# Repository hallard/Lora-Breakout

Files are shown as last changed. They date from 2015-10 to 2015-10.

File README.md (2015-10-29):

RFM92 RFM95 RFM96 RFM98 Lora breakout board NRF24L01 socket
===========================================================

This is a utility breakout board for connecting Lora device onto 
NRF24L01 sockets

this breakout add also some other nice feature : 
- **Added** ATSHA204 for Crypto Authentication.
- **added** a Led to see what's going on.

Breakout comes in two versions, one with classic 2x4 PTH connector and the other with the same
but SMD version of the connector, this permit to have the PCB quite the same size of the original
RFM modules size. Oh, also these boards are rounded instead of corners.

This has been created to work with [ULPNode][7] Project and [ArduiPi][4] Project, but this breakout
can be used anywhere where you use NRF24L01 or has NRF24L01 connector.

The same breakout board exists also for RFM69W and RFM69HW on this [repo][2] and for RFM12B on this [one][1].
 
Check out news and other on my [blog][5], Any comments or question are welcomed on the [community][8]!

Detailed Description
====================

Everything will be soon documented on this dedicated [post][6].

## PTH connector version

### Schematic  
schematic  

### Boards  
board&nbsp;
top&nbsp;
bottom

You can direct order PCB from this [link][10] to OSHPark.

## SMD connector version

### Schematic  
schematic  

### Boards  
board SMD&nbsp;
top SMD&nbsp;
bottom SMD

You can direct order PCB from this [link][11] to OSHPark.

Check out news and other on my [blog][5], Any comments or question are welcomed on the [community][8]!

[1]: https://github.com/hallard/RFM12B-BreakOut
[2]: https://github.com/hallard/RFM69W-BreakOut
[3]: http://hallard.me/rfm12b-breakout/ 
[4]: http://hallard.me/arduipi
[5]: http://hallard.me
[6]: http://hallard.me/lora-breakout/ 
[7]: http://hallard.me/category/ulpnode/
[8]: https://community.hallard.me/
[10]: https://oshpark.com/projects/XCiquSkv/order
[11]: https://oshpark.com/projects/V7WQxHGe/order

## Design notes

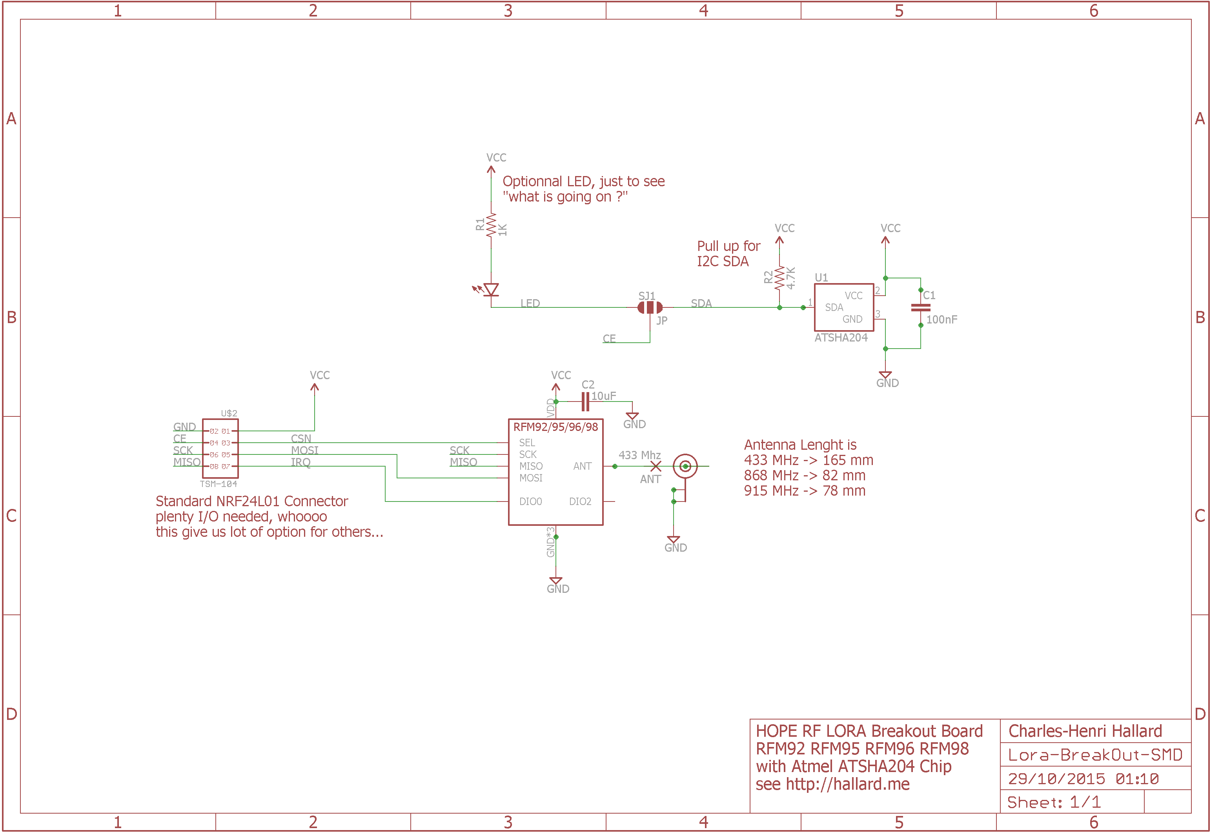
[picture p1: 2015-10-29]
Lora-Breakout-SMD-sch.png

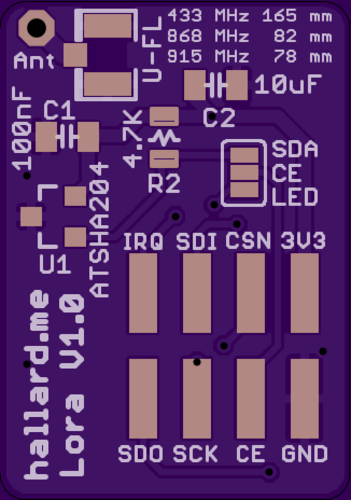
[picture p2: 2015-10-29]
Lora-Breakout-SMD-bot.png

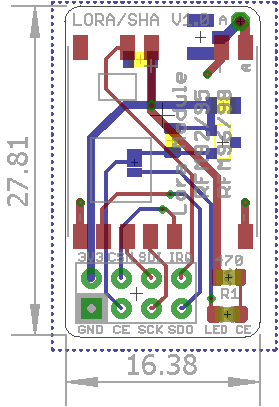
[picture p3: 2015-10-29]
Lora-Breakout-brd.png

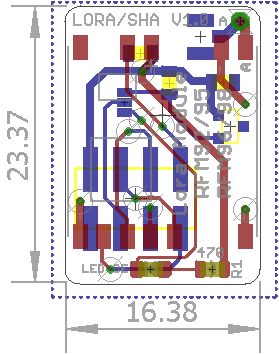
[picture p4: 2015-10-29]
Lora-Breakout-SMD-brd.png

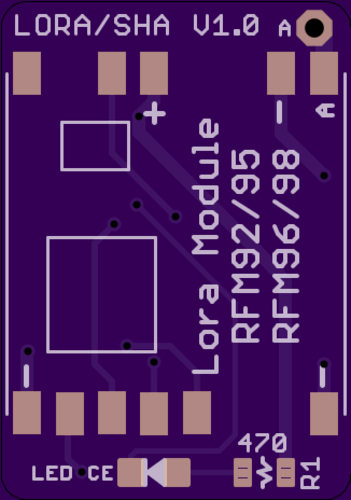
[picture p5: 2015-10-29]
Lora-Breakout-SMD-top.png

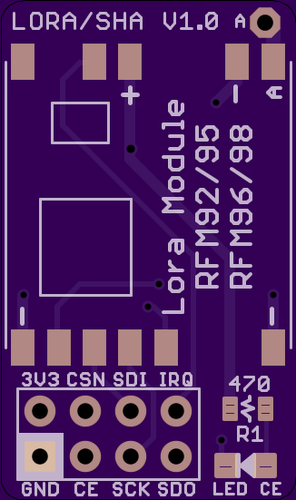
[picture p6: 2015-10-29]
Lora-Breakout-top.png

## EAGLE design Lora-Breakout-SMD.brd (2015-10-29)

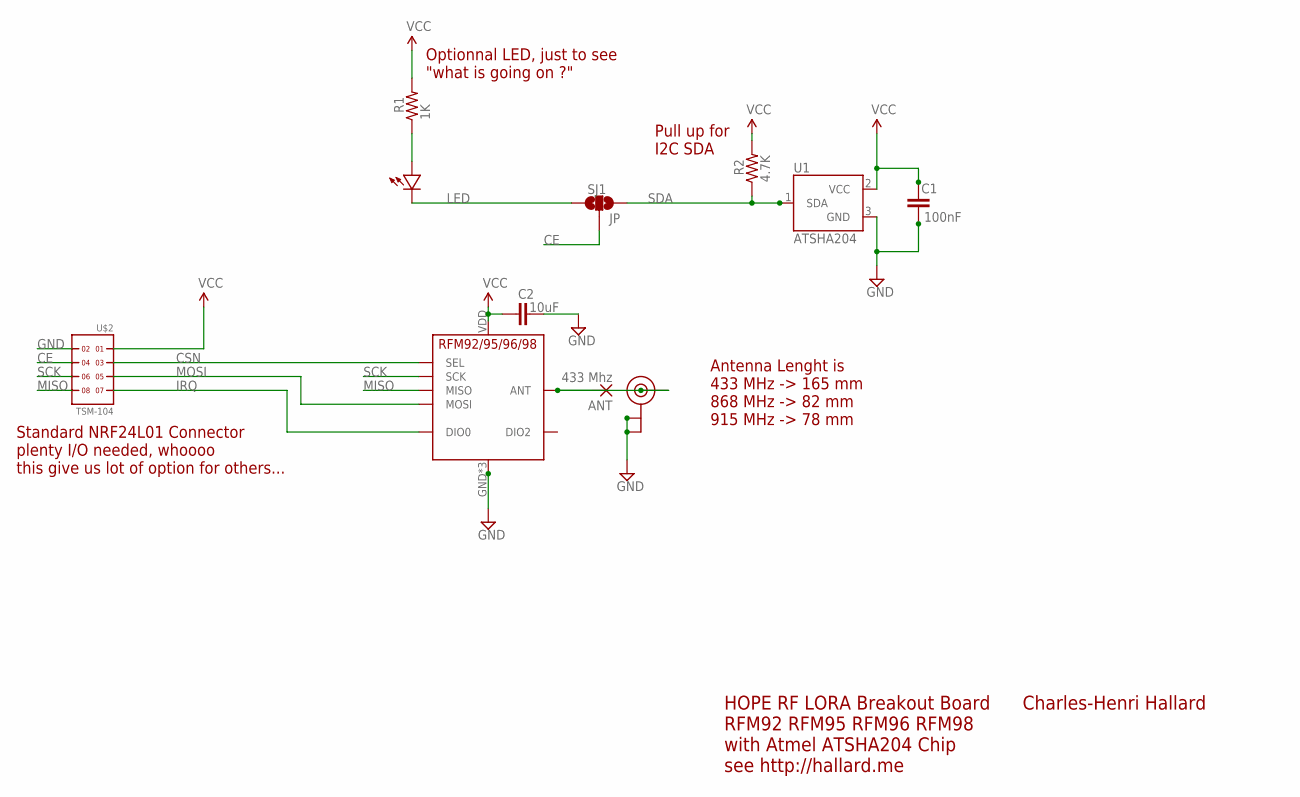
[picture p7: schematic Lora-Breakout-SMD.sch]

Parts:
ANT: 433 Mhz; 1,6/0,8
C1: 100nF; 0805-CAP
C2: 10uF; 0805-CAP
R1: 1K; 0805-RES
R2: 4.7K; 0805-RES
SJ1: JP; PAD-JUMPER-3-NO_YES_SILK
U1: ATSHA204; SOT23-3
U$1: LED0805-LARGE; 0805-LED-LARGEPADS
U$2: TSM-104
U$3: RFM95
U-FL: U.FL

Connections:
CE: SJ1.2, U$2.4
CSN: U$2.3, U$3.NSS (SEL)
GND: C1.2, C2.2, U1.3 (GND), U$2.2, U$3.GND, U$3.GND1 (GND), U$3.GND2 (GND), U-FL.1 (GND), U-FL.2 (GND)
IRQ: U$2.7, U$3.DIO0
LED: SJ1.1, U$1.MINUS
MISO: U$2.8, U$3.MISO
MOSI: U$2.5, U$3.MOSI
unnamed: ANT.1, U$3.ANT, U-FL.3 (SIGNAL)
unnamed: R1.1, U$1.PLUS
SCK: U$2.6, U$3.SCK
SDA: R2.1, SJ1.3, U1.1 (SDA)
VCC: C1.1, C2.1, R1.2, R2.2, U1.2 (VCC), U$2.1, U$3.VDD (VCC)

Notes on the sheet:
HOPE RF LORA Breakout Board RFM92 RFM95 RFM96 RFM98 with Atmel ATSHA204 Chip see http://hallard.me
Charles-Henri Hallard
Antenna Lenght is 433 MHz -> 165 mm 868 MHz -> 82 mm 915 MHz -> 78 mm
Optionnal LED, just to see "what is going on ?"
Standard NRF24L01 Connector plenty I/O needed, whoooo this give us lot of option for others...
Pull up for I2C SDA

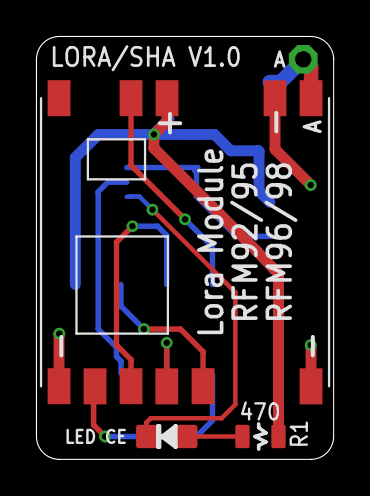
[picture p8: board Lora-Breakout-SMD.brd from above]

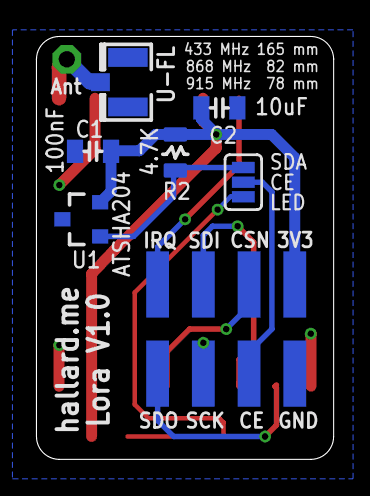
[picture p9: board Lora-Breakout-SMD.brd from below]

Board: 2 copper layers, 16.5 x 23.5 mm, 11 parts (7 on the bottom side), 12 nets.

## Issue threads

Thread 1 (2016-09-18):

SJ1

alex1sh, 2016-09-18:
Hi,

Would you please help to understand the SJ1? It contains the following:
- SDA
- CE
- LED

How do I wire it please? Do I hook up SDA or CE to LED?

Thanks
Alex

hallard, 2016-09-19:
@alex1sh
SJ1 is just for some feature, you don't need it for Lora, but if you connect
If you want to map CE to LED just put solder between CE and LED of SJ1
If you want to use ATSHA then, just put solder between CE and SDA of SJ1, the CE pin is used as SDA to drive ATSHA chip, but in this case you'll need to write the code to use this chip.

alex1sh, 2016-10-02:
@hallard - many thanks. Can I drive both LED and ATSHA with CE, i.e. solder all three pads of SJ1?
Yes, the code (MySensors) does handle ATSHA204A

hallard, 2016-10-03:
It should, but you need to try, and talking to ATSHA will override led state ;-)

Closed 2016-10-17.

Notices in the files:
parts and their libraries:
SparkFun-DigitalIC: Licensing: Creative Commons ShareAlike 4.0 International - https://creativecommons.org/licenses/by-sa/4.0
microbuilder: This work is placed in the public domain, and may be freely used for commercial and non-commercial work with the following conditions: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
